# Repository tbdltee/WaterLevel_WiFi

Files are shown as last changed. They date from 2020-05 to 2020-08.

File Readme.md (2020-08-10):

# Wireless Water Level measurement
This project is using HC-SR04p ultrasonic to measure the water level and send to internet dashboard (using node-red).

## Current status: up
 * dashboard url: www.tbdltee.cloudns.cl:8890
 * Linenoify service was inactive. Plan to migrate to LINE-bot for notification. 
 
## Firmware Upload Status (Arduino/ESP8266)

* IOT001D0001 - 00410/00410/SDK2.2.1-Boot1.7/Core 2.6.3
* IOT001D0002 - 0040E/0040E/SDK2.2.1-Boot1.7/Core 2.4.2
* IOT001D0003 - 0040E/0040E/SDK2.2.1-Boot1.7/Core 2.6.3

## Release History
* 0040G
  * change server from tbdltee.thddns.net to myiot.tbdltee.cloudns.cl
  * dashboard url: www.tbdltee.cloudns.cl:8890
* 0040F
  * improve TCP response handling speed.
  * change iot server from tbdltee.duckddns.org:10722 to tbdltee.thddns.net:8895
  * change OTA server from tbdltee.duckddns.org:8890 to tbdltee.thddns.net:8890
  * BME280 auto reset if cannot read data for consecutive 5 times
  * Support Submersible 4-20mA Water Level Sensor
* 0040E
  * Support remote reboot device from Dashboard
* 0040D
  * fixed: WiFiConfig portal handling
	* WiFiConfig redirect page to root if page not found.
	* WiFiConfig portal show WiFi signal strength bar instead of text
	* ESP is now graceful shutdown. Make WiFi connection more stable.
	* Increase TCP timeout from 10s to 15s
	* Increase UDP timeout from 3s to 5s
	* restart node if cannot connect to internet for 1 day.
  * 3G TxiNET_LowBatt from 10 hrs to 6 hrs.
  * bugs fixed (Arduino) in RainCount debounce using millis(). millis() is not working while sleep. Change millis() to Debounce_counter
	* bugs fixed (Arduino) in %Batt calculation. limited min/max Volt to 3400/4100.
	* Arduino: Sent lastCM to internet instead of average value. Last 5 values use for STD DV calculation.
  * Rain_debounce_counter set to 150ms
  * Timer adjustment
  * Change method to get Batt level. Measure Vcc for stability and use Max A2-value as 100%. Decrease maxADC 50mV for every 7 days.
	* Increase Batt_0% from 3.4v to 3.6v to increase stability at low batt mode
* 0040C
  * Measure ADC of internal reference 1.1v and calc back to A2-ADC.
  * Support Battery auto-calibration.
  * Bug fixed when Tx come back from Power-Off state
* 0040B
  * Use hardware jumpper to select between 3G and WiFi profile
  * Change WiFi update interval from 5 to 10 min
  * Update with TCP, then use UDP if TCP failed.
  * Change device key to Sequence Number
  * device is sent with raw distance data. Water level is calculated on the server.
  * Support line notification
  * Support only BME280 to simplify the code. 
  * Support hPA measurement from BME280
  * Change tempC value from 0..100 to tempC+40 (0..125 -> -40..85) to support full range of BME280
* 00400
  * release based on Water_Level_v4

## About the code
The code consists of 4 sketches:
* Arduino_WiFi:       this is a code for Arduino Pro-Mini. Upload the code using USB-TTL adapter.
* ESP_NodeRed_WiFi:   this is a code for ESP8266-01. Upload the code using USB-TTL adapter or HTTP OTA.
* esp_fota.js:        NodeJS app for http OTA update.
* node-red_flow.json: Node-Red flow

Configure 3G-WiFi USB dongle for deivceID IOT-xxxxDyyy:
* ssid: IOT-xxxxDyyy-3G
* pass: IOT-xxxxDyyy-3G
* ssid broadcast: off
* Security Type: WPA2-Personal, WPA-algorithm: TKIP+AES
* DHCP: off
* 3G dongle IP/Subnet: 192.168.8.1/255.255.255.0

Configure Line Notification (de-preciated. Replaced by LINE-bot):
* Add 'Line Notify' as friend in LINE app.
* goto https://notify-bot.line.me/th/ and log-in with your LINE id
* Click menu on  the top-right of the page and select  'My Page'
* Click 'Generate Token'
* Enter 'Token name' and chat group to notify.
  * Token Name: My IOT
  * Chat Group: 1-on-1 chat with Line Notify
  * Click 'Generate Token'
* copy the token and update in the Deivce_list databased
* if no line token is define, LINE nitification will be disable for those devices.

## How to use:
* Each device has it own Device ID (IOT-xxxxDyyy)
  * Group ID: IOT-xxxx
  * ID: Dyyy
* Select internet access profile using Jumper:
  * open: 3G profile
  * short: WiFi profile
  * when WiFi profile is select, the previous WiFi configuration is used.
* 3G configutation: none
* WiFi configuration:
  * Power-off and then on the device
  * Wait until device enter config mode
  *	Connect to ssid: iotConfAP, pass:iot1234 (if ask)
  *	Open browser and goto http://192.168.4.1
  * Enter wifi info, SAVE and wait for device to reboot
* LED status:
  * Fast blink:   OTA
  * Flash:        modem power up
  * Double flash: Connecting to internet
  * Triple flash:	sending data
  
## Author

Teerapong S. –  [tbdltee@gmail.com]

Patent Pending (Reg.1701003801)

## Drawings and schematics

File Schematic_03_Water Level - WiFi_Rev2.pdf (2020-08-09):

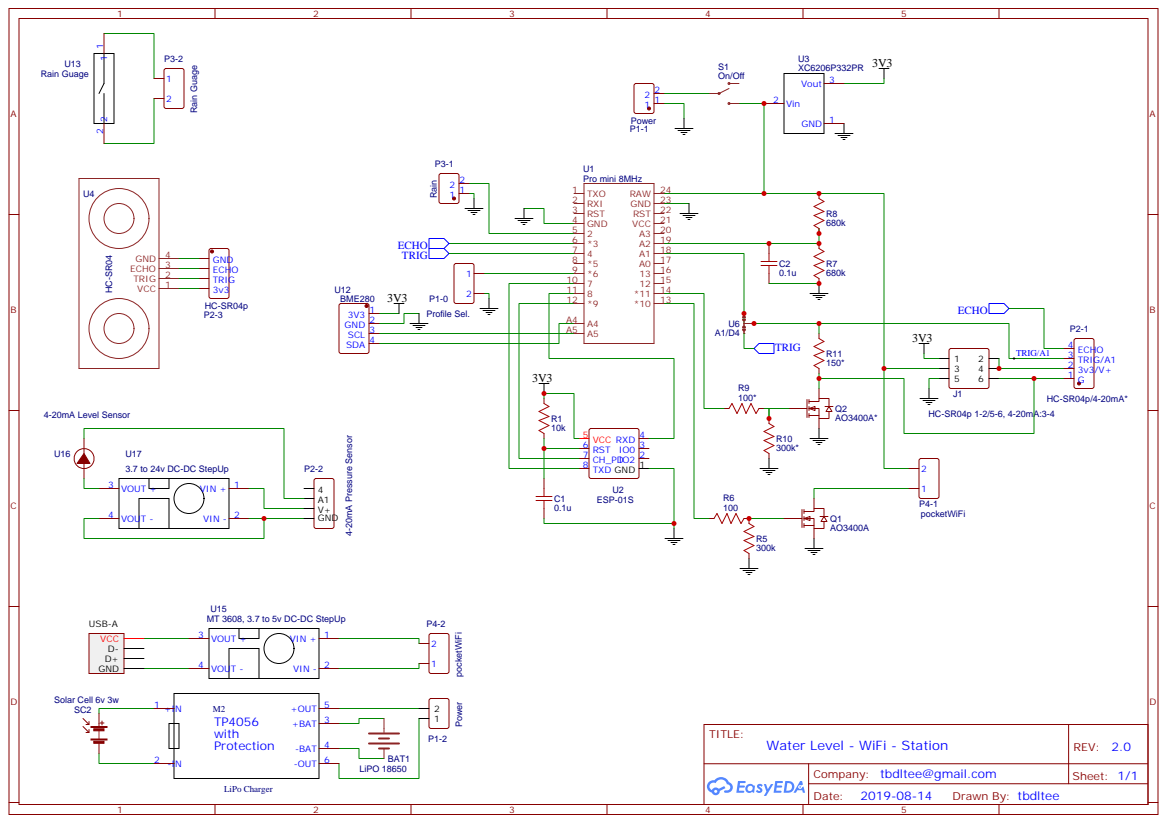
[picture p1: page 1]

Company: tbdltee@gmail.com

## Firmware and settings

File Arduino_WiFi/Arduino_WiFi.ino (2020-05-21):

#define stDEBUG             1               // Show Debug message. 0-no debug, 1-show debug, 2-debug using wifi profile
#define SENSOR_TYPE         0               // Distance Sensor:    0-Top-Down distanceCM (HC-R04), 1-Buttom-up 4-20mA, 2-reserved, 3-reserved
#define SENSOR_RAIN         1               // Rain Gauge Sensor:  0-not present, 1-present

// ================================= Node Info. ===========================================
// SW version 0040D 
const char* Device_GroupID  = "IOT-0001";   // Device_GroupID
const char* Device_ID       = "D001";       // Device ID

// =================================== Library Declaration ================================
#include "Node_Config.h"
#include <avr/wdt.h>          // library for default watchdog functions
#include <avr/interrupt.h>    // library for interrupts handling
#include <avr/sleep.h>        // library for sleep
#include <avr/power.h>        // library for power control
#include <NeoSWSerial.h>
#include <EEPROM.h>
#include <I2C.h>
#include <BME280_I2C.h>

#define inRange(x, a, b) (((a) <= (x)) && ((x) <= (b)))     // define macro if (x>=a) && (x<=b)
#define outRange(x, a, b) (((x) < (a)) || ((x) > (b)))      // define macro if (x<a) || (x>b)
#define BYTE2HEX(x) ((((x) > 0x0F)?"":"0") + String((x), HEX))
#define LEDon() digitalWrite(LED_BUILTIN, HIGH)
#define LEDoff() digitalWrite(LED_BUILTIN, LOW)
#define LEDflash() ({digitalWrite(LED_BUILTIN, HIGH); delay(10); digitalWrite(LED_BUILTIN, LOW);})
#define LEDtoggle() (digitalWrite(LED_BUILTIN, !digitalRead(LED_BUILTIN)))

// Timers & Counters
volatile uint8_t  cnt1secWDT  = 0;            // Counter for 1 sec
volatile uint8_t  INT0_btnCnt = 0;            // INT0 Debounce Counter 10x15 = 150ms, (millis() not working in sleep mode)
volatile uint16_t cntRemaining;               // how many times remain before wakeup and tx value, Volatile variable, to be able to modify in interrupt function
volatile uint16_t RainCount   = 0;            // rain sensor counter

uint8_t TxiNETcnt     = 0;                    // Counter to send data to internet. 0-Send data, 1..250-Normal/Low Batt, 251..254-Pwr-Off recovery, 255-never send, 
uint8_t Rapidcnt      = 128;                  // Counter of rapid update
uint32_t wakeup_time  = 0;
String iNETSerialmsg  = "";

NeoSWSerial iNETSerial(ESP_RxPin, ESP_TxPin); // RX, TX
BME280 myBME280;

void(* resetFunc) (void) = 0;                 //declare reset function @address 0

// ============================================================================================
void setup() {
  wdt_disable();
  delay (500);                                // startup delay to avoid power surge
# if (stDEBUG > 0)
  Serial.begin(57600);
#endif

  pinMode (Profile_SEL_Pin,  INPUT_PULLUP);
  pinMode (ESP_ENpin, OUTPUT);
  digitalWrite(ESP_ENpin, LOW);               // disable ESP8266
  pinMode (MODEM_ENpin, OUTPUT);
  digitalWrite(MODEM_ENpin, LOW);             // disable 3G/4G modem
  pinMode (LED_BUILTIN, OUTPUT);
  LEDoff();

  if ((digitalRead (Profile_SEL_Pin) == LOW) || (stDEBUG == 2)) {               // change from 3G to WiFi
    Device_Profile  = "WL";                   // use WiFi Profile
    ModemWaitTime   = 0;                      // wait for modem to power-up
    ModemPwrUpTime  = 50;                     // total modem power-up time 50s
    CMDdelayTime    = 0;                      // delay time after wifi connected
    WakeUpInterval  = 120;                    // device wake-up every 120s
    Batt_Interval   = 5040;                   // Batt re-calibration interval: 5 040 x 120 = 604 800 sec = 7 days
    iNET_ERR_RST    = 720;                    // Consecutive wifi error before node restart: 720 x 120 = 86 400 sec = 1 days
    TxiNET_LowBatt  = 60;                     // Send data to internet every 120min (WakeUpInterval x TxiNET_Normal)
    TxiNET_Normal   = 5;                      // Send data to internet every 10min (WakeUpInterval x TxiNET_Normal)
    printDEBUG (F("[S] == SYSTEM INIT (WiFi Profile) =="));
  } else {
    printDEBUG (F("[S] == SYSTEM INIT (3G Profile) =="));
  }
  printDEBUG ("[S] DeviceID: " + sysVar.DevID);
  pinMode (Profile_SEL_Pin,  INPUT);          // change pinMode to remove Internal R pullup
  
  randomSeed(get_rand_byte());
  iNetTx.seqNr = random(65536);
  iNETSerial.begin(19200);
  delay (200);
  Init_Peripheral();
  Initialize_wdt();                           // configure with reset interval 1 sec and start the watchdog.
  resetTxData ();
  sysVar.ssid = sysVar.DevID + "-" + String (Device_Profile);
  sysVar.pass = sysVar.ssid;
#if (SENSOR_TYPE == 1)
  EEPROM.get (0x00, ADC4mA);
#endif
}

void loop(void) {
  wakeup_time = millis();
  cntRemaining = WakeUpInterval * 1.2;
  updateBattState ();
  uint16_t PrevdistanceCM = TxData.lastCM;                            // save current distance value before new distance measurement
  measureDistanceCM ();                                               // single measure distance, every wake-up (3 min)
  checkLevelRapidChange (PrevdistanceCM);
  //printDEBUG ("[D] rangeCM-"+String(TxData.distanceIdx)+":"+String(TxData.lastCM) + ", Batt:"+String(iNetTx.BattLvl)+", RainCnt:"+String(RainCount)+", Rapidcnt:"+String(Rapidcnt));
  
  if (TxiNETcnt == 0) {                                 // Send data to internet
    updateData ();
    if (iNetTx.BattLvl <= BATTPowerSave) {
      TxiNETcnt = TxiNET_LowBatt;                       // if low batt, set TxInterval to TxiNET_LowBatt
    } else {
      TxiNETcnt = TxiNET_Normal;
    }
  }
  if (SYScnt.iNetRst > iNET_ERR_RST) {
    //printDEBUG ("[S] No iNET 24hr...Restart");
    delay (500);
    resetFunc();
  }
  sleep();
  TxiNETcnt--;
}

void checkLevelRapidChange (uint16_t PrevdistanceCM) {
  uint16_t LvlRapidCM = LvlCMChange * WakeUpInterval / 60;            // calc cm/min to cm threshold per measurement
  uint16_t lowerRapid =  (PrevdistanceCM > LvlRapidCM) ? PrevdistanceCM - LvlRapidCM: 0;
  if (TxData.lastCM  > 0) {
    if (TxData.lastCM > (PrevdistanceCM + LvlRapidCM)) {              // distance above threshold -> Rapid change increase counter
      Rapidcnt++; SYScnt.nonRapid = 0;
    } else if (TxData.lastCM < lowerRapid) {                          // distance below threshold -> Rapid change decrease counter
      Rapidcnt--; SYScnt.nonRapid = 0;
    } else {                                                          // distance within threshold range -> increase non-rapid counter
      SYScnt.nonRapid++;
      if (SYScnt.nonRapid > 10) {                                     // if non-rapid counter > 10, reset rapid change counter
        Rapidcnt = 128; SYScnt.nonRapid = 0;
      }
    }
    if (outRange (Rapidcnt, 125, 131)) {                              // if 3 consecutive rapid change, update inet/override BATTPowerOff
      TxiNETcnt = 0; Rapidcnt = 128;
      sysVar.NodeStatus |= 0x08;                                      // Set Rapid Update flag
    }
  }
}

void updateBattState (void) {
  SYScnt.BattreCal++;
  iNetTx.BattLvl = getBatt();                                       // get %battery
  //printDEBUG ("[Batt] max-mV:" + String(sysVar.maxAmVolt) + ", BattCnt:"+ String(SYScnt.BattreCal) + " ,TxiNETcnt:"+ String(TxiNETcnt));
  LEDflash ();
  if (iNetTx.BattLvl <= BATTPowerOff) {                             // if Batt_PowerOff, set TxiNETcnt = 254 (never update iNET)
    TxiNETcnt = 255;
    //printDEBUG ("[D] Batt Power-Off..");
   return;
  }
  if (TxiNETcnt > 250) {                                            // if Batt in Power_off state, check wakeup condition?
    if (iNetTx.BattLvl > BATTPowerSave) {                           // if Batt Level above Power_Save, decrease counter
      //printDEBUG ("[D] Batt Recovery.." + String (TxiNETcnt - 251));
    } else {                                                        // Tx in Power-Save with below Power_Save threshold -> hold in receovery state
      TxiNETcnt = 254;
      //printDEBUG ("[D] Batt Reovery-hold..");
    }
    if (TxiNETcnt == 251) {                                         // Batt above Power_Save for 4 consecutive WakeupInterval, send data to iNET
      if (iNetTx.BattLvl <= BATTPowerSave) sysVar.NodeStatus |= 0x10;
      else sysVar.NodeStatus &= 0xEF;
      TxiNETcnt = 0;
    }
    return;
  }
  // not in recovery state
  if (iNetTx.BattLvl <= BATTPowerSave) {                            // if Batt Level above Power_Save, decrease counter
    if ((sysVar.NodeStatus & 0x10) == 0) {                          // Normal ==> Power Save
      sysVar.NodeStatus |= 0x10;                                    // Low Batt
      if (TxiNETcnt > 0) TxiNETcnt += (TxiNET_LowBatt - TxiNET_Normal);
      //printDEBUG ("[D] Batt Norm -> PwrSave...new TxiNETcnt:" + String (TxiNETcnt));
    }
  } else {                                                          // Normal state
    if (sysVar.NodeStatus & 0x10) {                                 // Power Save ==> Normal
      sysVar.NodeStatus &= 0xEF;                                    // Normal Batt
      TxiNETcnt = TxiNET_LowBatt - TxiNETcnt;
      if (TxiNETcnt >= TxiNET_Normal) TxiNETcnt = 0;
      else TxiNETcnt = TxiNET_Normal - TxiNETcnt;
      //printDEBUG ("[D] Batt PwrSave -> Norm...new TxiNETcnt:" + String (TxiNETcnt));
    }
  }
}

void resetTxData (void) {
  iNetTx.LvErrType      = 1;
  iNetTx.distanceCM     = 0;
  iNetTx.TempC          = 127;
  iNetTx.RH             = 127;
  iNetTx.hPAx100        = 0xFFFF;
  iNetTx.LvSampleRead   = 0;
  iNetTx.iNETattempt    = 0;
  iNetTx.iNETDNSfail    = 0;
  iNetTx.iNETSentfail   = 0;
  iNetTx.iNETWififail   = 0;
  iNetTx.iNETHostfail   = 0;
  if ((sysVar.NodeStatus & 0x04) == 0) iNetTx.iNETNoResp = 0;
}

void getSensorData (void) {       // calculate average distance and get weather data
  
  return;
  
  getAvgDistance ();              // iNetTx.distanceCM and iNetTx.errType were updated
  float TempC = 127, RH = 127, Pa = 0;
  readBME280 (myBME280, TempC, Pa, RH);
  if (myBME280.ready < 1) {
    TempC = 127; RH = 127; Pa = 0;
  }
  if (isnan(TempC)) TempC = 127;
  if (isnan(RH)) RH = 127;
  if (isnan(Pa)) Pa = 0;
  iNetTx.TempC    = (uint8_t)((TempC == 127)?127:(TempC+40));
  iNetTx.RH       = (uint8_t)RH;
  iNetTx.hPAx100  = (uint16_t)(outRange(Pa, 50000, 115500)?0xFFFF:(Pa-50000.0));
  if ((TempC == 127)||(RH == 127)||(Pa == 0)) SYScnt.BME280err++;
  else SYScnt.BME280err = 0;
  if (SYScnt.BME280err > BME280err_ALLOW) {
    myBME280.reset();
    BME280_Init (myBME280);
    SYScnt.BME280err = BME280err_ALLOW - 1;
  }
}

String getValue(String data, char separator, int index) {
  int found = 0;
  int strIndex[] = {0, -1};
  int maxIndex = data.length()-1;
  for (int i = 0; i <= maxIndex && found <= index; i++) {
    if (data.charAt(i) == separator || i == maxIndex) {
      found++;
      strIndex[0] = strIndex[1]+1;
      strIndex[1] = (i == maxIndex) ? i+1 : i;
    }
  }
  return found>index ? data.substring(strIndex[0], strIndex[1]) : "";
}

uint16_t calcSleepTime (void) {                   // calculate sleep time (sec) to prevent wake-up time > WakeUpInterval, e.g OTA
  uint16_t runningTime = (uint16_t)((millis() - wakeup_time)/1000L);
  runningTime = runningTime % WakeUpInterval;     // calc running time of the last cycle to ensure that runningtime < WakeUpInterval
  return (WakeUpInterval - runningTime);
}

String uint16_t2HEX (uint16_t value) {
  String result = BYTE2HEX((uint8_t)((value & 0xFF00) >> 8));
  result += BYTE2HEX((uint8_t)(value & 0x00FF));
  return result;
}

// ========================= Generate true random number, use for RandomSeed() ============================
int GetTemp (void) {
  unsigned int wADC;
  ADMUX = (_BV(REFS1) | _BV(REFS0) | _BV(MUX3));
  ADCSRA |= _BV(ADEN);  // enable the ADC
  delay(20);            // wait for voltages to become stable.
  ADCSRA |= _BV(ADSC);  // Start the ADC
  while (bit_is_set(ADCSRA,ADSC));
  wADC = ADCW;
  return (wADC);
}

int coin_flip(void) {
  int little_bit;
  return little_bit = (GetTemp() & 1);
}

int getFairBit(void) {
  while(1) {
    int a = coin_flip();
    if (a != coin_flip()) return a;
  }
}

int get_rand_byte(void){
  int n=0;
  int bits = 7;
  while (bits--) {
    n<<=1; 
    n |= getFairBit();
  }
  return n;
}

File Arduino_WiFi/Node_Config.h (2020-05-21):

// =================================== Paramteres ================================
String Device_Profile   = "3G";         // 3G profile parameter
uint8_t ModemWaitTime   = 10;           // wait for modem to power-up
uint8_t ModemPwrUpTime  = 75;           // total modem power-up time 75s
uint8_t CMDdelayTime    = 5;            // delay time after wifi connected
uint16_t WakeUpInterval = 300;          // device wake-up every 5min
uint16_t Batt_Interval  = 2016;         // Batt re-calibration interval: 2016 x 300 = 604 800 sec = 7 days
uint16_t iNET_ERR_RST   = 288;          // Consecutive wifi error before node restart: 288 x 300 = 86 400 sec = 1 days
uint8_t TxiNET_LowBatt  = 72;           // Max:250, Send data to internet every 6hr (WakeUpInterval x TxiNET_Normal)
uint8_t TxiNET_Normal   = 6;            // Max:250, Send data to internet every 30min (WakeUpInterval x TxiNET_Normal

// Sensor pin: |GND|Rain| |SR04_TRIG|SR04_ECHO|GND|A1|5V|3V3|
// pin assignment
const uint8_t RainGauge_pin   = 2;
const uint8_t BattMeasurepin  = A2;
const uint8_t Profile_SEL_Pin = 6;            // Profile Select: 0-WiFi, 1-3G

#if (SENSOR_TYPE == 0)                        // HC-SR04
  const uint8_t SR04_TRIGpin  = 3;
  const uint8_t SR04_ECHOpin  = 4;
  const uint16_t LvlCMChange  = 10;           // Update data asap if levelCM change > 10 cm/min
#elif (SENSOR_TYPE == 1)                      // 4-20mA Buttom-up Sensor ,e.g Sumersible water level sensor
  #define ADC4mAINIT            192
  const uint8_t  Level_pin    = A1;
  const uint8_t  Level_EN_pin = 11;
  const uint16_t LvlCMChange  = 20;           // Update data asap if levelCM change > 10 cm/min --> ADC=20
  uint16_t       ADC4mA       = ADC4mAINIT;   // Normalize ADC value 4mA @3.3v. Run ADC_Cal.ino sketch to get value
  uint8_t        minADC4mAcnt = 0;            // consecutive counter of ADC below ADC4mA
#endif

const uint8_t ESP_RxPin       = 7;            // to ESP Tx
const uint8_t ESP_TxPin       = 8;            // to ESP Rx
const uint8_t ESP_ENpin       = 9;            // ESP enabled (CHPD pin)
const uint8_t MODEM_ENpin     = 10;           // Pocket WiFi enable pin

// ============================= Threshold =============================
const uint8_t  OTA_ATTEMPT_ALLOW  = 5;        // ESP8266 http OTA: 0-OTA not allow, 1..7-#of OTA failure allow
const uint8_t  BATTPowerSave      = 30;       // %Batt to operate in power save mode
const uint8_t  BATTPowerOff       = 10;       // %Batt to operate in power off
const uint16_t BATT_V000          = 3600;     // Batt mVolt as 0%Batt, 3.40v = Vcc 3.15v + 0.25v drop voltage
const uint8_t  BME280err_ALLOW    = 5;        // Consectutive BME280 read error before BME280 reset

// ============================= Variable =============================
struct counter {
  uint8_t  OTAallow     = OTA_ATTEMPT_ALLOW;  // #OTA update failure before stop OTA. reset when data sent with no OTA req.
  uint8_t  nonRapid     = 0;                  // Counter of consecutive non-rapid count to reset Rapidcnt counter
  uint8_t  BME280err    = 0;                  // consecutive error reading BME280
  uint16_t BattreCal    = 0;                  // batt re-calibrate counter
  uint16_t iNetRst      = 0;                  // Consecutive wifi error counter before node restart
} SYScnt;

struct sysParaType {                          // system parameters
  String   DevID          = String(Device_GroupID) + String(Device_ID);
  String   ssid           = "";
  String   pass           = "";
  uint8_t  NodeStatus     = 0x80;             // Node Status: 7654 3210, 7:node reboot, 6:Rain Sensor-ready, 5:Weather sensor, 4:Low Batt, 3:Rapid Update, 2:Server-No response, 1/0: Send retry
  uint16_t WiFiConfTime   = 600;              // Wifi Config mode time-out, 5 min. Allow only after Arduino reset
  uint16_t maxAmVolt      = 4100;             // max mV of ADC value
} sysVar;

struct NodeDataType {
  uint16_t lastCM         = 0;                // lastast distanceCM
  uint8_t  distanceIdx    = 0;                // index of distanceMM[]
  uint16_t accRainCount   = 0;                // accumulated rain counter
  uint16_t distanceCM[5]  = { 0,0,0,0,0 };
} TxData;
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

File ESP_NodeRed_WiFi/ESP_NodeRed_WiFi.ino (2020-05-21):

#include <Arduino.h>
#include "Node_Config.h"
#include <EEPROM.h>
#include <ESP8266httpUpdate.h>
#include <ESP8266WiFi.h>
#include <WiFiUdp.h>
#include <ESP8266WebServer.h>

uint8_t ESPstatus = 0;
uint8_t strCMDidx = 0;
uint8_t OTAallowCnt = 0;
String CMDSerial = "", strCMD = "", devID = "", sendTxt = "", SEQNr = "";
uint32_t prevtime = 0;

char ssid[32] = "test";
char pass[32] = "test";

ESP8266WebServer server(80);              // local web server for configuration portal
IPAddress Host_addr(255,255,255,255);
WiFiUDP udpClient;

// ======================== Program Setup Part ===========================
void setup() {
  WiFi.mode (WIFI_OFF);
  WiFi.forceSleepBegin();
  delay (1);                                              // turn-off RF at Power-up
  
  pinMode(LED_BUILTIN, OUTPUT);
  digitalWrite(LED_BUILTIN, HIGH);                        // turn-off LED
  
  Serial.begin (19200);                                   // Init COMM to communicate with Arduino
  delay (100);
  Serial.println ("\r\n\r\nC,ESP init");
  prevtime = millis();
  while (((millis() - prevtime) < 10000L) && (ESPstatus == 0)) {
    monitorSerial();                                        // wait for command from Arduino
  }
  if (ESPstatus == 0) {                                     // time-out
    ESP.restart();
  } else if (ESPstatus == 1) {                              // coonect with 3G profile
    Serial.println ("C,connecting 3G with " + String(ssid));
    Connect2WiFi (0);
  } else if (ESPstatus == 6) {                              // connect using WiFi profile
    Serial.println ("C,connecting wifi.." + String(ssid));
    Connect2WiFi (1);
  } else if (ESPstatus == 7) {                              // connect using WiFi Manager
    ReadWiFiConfig ();                                      // use local ssid/pass
    Serial.println ("C,connecting wifi with wifiConfig.." + String(ssid));
    Connect2WiFi (2);
    if (ESPstatus == 2) Serial.println ("C,Config ok," + String (ssid) + ","+String(pass));
  }
  
  if (ESPstatus == 2) {                                     // wifi connected
    Serial.println ("C,wifi ready,IP:" + WiFi.localIP().toString());
    udpClient.begin(dataPort);
  } else if (ESPstatus == 7) {                              // wifi.begin failed and in wifi config mode
    Serial.println ("C,Enter wifi config mode");
    ESPstatus = 5;
    startConfigPortal (600);                                // startConfigPortal result in ESP rertart.
  } else {
    Serial.println ("C,Wifi connect error..TIME-OUT");
    Serial.println ("C,ESP ready to shut-down");
    WiFi.disconnect ();
    delay (80);
    ESP.deepSleep (10000000L, WAKE_RF_DISABLED);
    WiFi.forceSleepBegin();
    delay (30000);
    ESP.restart();
  }
  ReadHostAddr ();                                          // read Host address from EEPROM
}
//================= end of setup, ESPstate-2 ==============================

void loop() {
  uint8_t HostlookupFail = 0;
  if (ESPstatus == 2) {                               // wifi connected
    while (ESPstatus != 4) monitorSerial();           // wait for completed RCV Data
    ESPstatus = 10;                                   // Move Connecting to Hostname resolving State
    prevtime = millis() - 12000;
  } else if (ESPstatus == 10) {
    ResolveHostName ();
  } else if (ESPstatus == 11) {                       // Host Address presented
    sendData2iNet ();
    ESPstatus = 2;                                    // move to Wait for CMD
  }
  monitorSerial();
}

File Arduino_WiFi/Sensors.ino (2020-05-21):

void Init_Peripheral() {
#if (SENSOR_TYPE == 0)            // HC-SR04
  pinMode(SR04_TRIGpin, OUTPUT);
  digitalWrite(SR04_TRIGpin, LOW);
  pinMode(SR04_ECHOpin, INPUT);
#elif (SENSOR_TYPE == 1)          // 4-20mA Buttom-up Sensor ,e.g Sumersible water level sensor
  pinMode (Level_EN_pin, OUTPUT);
  digitalWrite(Level_EN_pin, LOW);
#endif

  pinMode(BattMeasurepin, INPUT);
  BME280_Init(myBME280);
  if (myBME280.ready > 0) {
    sysVar.NodeStatus |= 0x20;
    printDEBUG ("[S] Temp/RH: BME280..OK");
  } else {
    printDEBUG ("[S] Temp/RH: no BME280");
  }

  RainCount = 0;
#if (SENSOR_RAIN == 1)
  printDEBUG ("[S] Rain Gauge..OK");
  sysVar.NodeStatus |= 0x40;
  pinMode(RainGauge_pin, INPUT_PULLUP);                 // Set INT0 back to input-pullup
  attachInterrupt(digitalPinToInterrupt(RainGauge_pin), RainGaugeCount, FALLING);
#else
  printDEBUG ("[S] no Rain Gauge.");
#endif
  printDEBUG ("[S] WakeUpInterval: " + String(WakeUpInterval) + "\r\n");
}

uint8_t getBatt(void) {
  uint16_t Avalue   = 0;                                                  // ADC 0..1023, read 64 loop => ADC value = 0..65472
  uint16_t AmVolt   = 0;
  uint16_t A11Value = readADC11();                                        // read ADC @1.1v reference  
  uint16_t mVcc = map(1023, 0, A11Value, 0, 1100);                        // calculate Vcc

  if (sysVar.maxAmVolt < 4100) sysVar.maxAmVolt = 4100;                   // init maxAmVolt to 4.10v as 100%
  for (uint8_t i = 0; i < 64; i++) Avalue += analogRead(BattMeasurepin);
  AmVolt = map (Avalue, 0, 65472, 0, mVcc) * 2;                           // Calculate A2 volt. x2 due to R-divider
  if (SYScnt.BattreCal >= Batt_Interval) {                                // re-calibration counter expire,
    SYScnt.BattreCal = 0;
    sysVar.maxAmVolt -= 50;                                               // reduce maxAmVolt 50mV
  }
  
  if (AmVolt > sysVar.maxAmVolt) sysVar.maxAmVolt = AmVolt;
  // printDEBUG ("[B] Batt_cnt: "+ String(SYScnt.BattreCal)+" ("+ String(Batt_Interval)+"), Vcc: "+ String(mVcc)+", A-mV: "+ String(AmVolt)+", Amax-mV: "+ String(sysVar.maxAmVolt));
  if (AmVolt <= BATT_V000) {
    return 0;  
  } else {
    return (uint8_t)map(AmVolt, BATT_V000, sysVar.maxAmVolt, 0, 100);
  }
}

uint16_t readADC11() {          // set ADC reference to Vcc and read ADC of internal 1.1V reference
  #if defined(__AVR_ATmega32U4__) || defined(__AVR_ATmega1280__) || defined(__AVR_ATmega2560__)
    ADMUX = _BV(REFS0) | _BV(MUX4) | _BV(MUX3) | _BV(MUX2) | _BV(MUX1);
  #elif defined (__AVR_ATtiny24__) || defined(__AVR_ATtiny44__) || defined(__AVR_ATtiny84__)
    ADMUX = _BV(MUX5) | _BV(MUX0);
  #elif defined (__AVR_ATtiny25__) || defined(__AVR_ATtiny45__) || defined(__AVR_ATtiny85__)
    ADMUX = _BV(MUX3) | _BV(MUX2);
  #else
    ADMUX = _BV(REFS0) | _BV(MUX3) | _BV(MUX2) | _BV(MUX1);
  #endif  

  delay(2);                         // Wait for Vref to settle
  ADCSRA |= _BV(ADSC);              // Start conversion
  while (bit_is_set(ADCSRA,ADSC));  // measuring

  uint8_t low  = ADCL;              // must read ADCL first - it then locks ADCH  
  uint8_t high = ADCH;              // unlocks both
  uint16_t result = (high<<8) | low;
  return result;
}

void getAvgDistance (void) {        // average distace value in buffer to send to internet
  uint8_t i, countDistance1 = 0;
  uint16_t sumDistance = 0, sumErr = 0;
  
  iNetTx.LvSampleRead = TxData.distanceIdx;
  if (TxData.distanceIdx > 5) TxData.distanceIdx = 5;
  for (i = 0; i < TxData.distanceIdx; i++) {
    if (TxData.distanceCM[i] > 0) {
      sumDistance += TxData.distanceCM[i];
      countDistance1++;
      if (TxData.lastCM > TxData.distanceCM[i]) sumErr += (TxData.lastCM - TxData.distanceCM[i]);
      else sumErr += (TxData.distanceCM[i] - TxData.lastCM);
    }
  }
  if (countDistance1 == 0) {
    iNetTx.distanceCM = 0;
    iNetTx.LvErrType = 1;                         // cannot read distance
  } else {
    iNetTx.distanceCM = TxData.lastCM;            // send lastCM
    if (countDistance1 <= 3) {
      iNetTx.LvErrType = 2;                       // too low #sample
    } else {
      if ((sumErr * 2) > sumDistance) {           // Err > 50% - too high standard deviation
        iNetTx.LvErrType = 3;
      } else {
        iNetTx.LvErrType = 0;
      }
    }
  }
}

void measureDistanceCM(void) {                                // main function to get distance from short range and long range sensor
  TxData.lastCM = getDistanceSesnor();                        // get distance from Sensor
  TxData.distanceCM[TxData.distanceIdx % 5] = TxData.lastCM;  // keep only last 5 samples
  TxData.distanceIdx++;
}

#if (SENSOR_TYPE == 0)                                // HC-SR04
uint16_t getDistanceSesnor() {                       // Get distance (mm), single ping from HC-SR04+
  uint16_t result = 0;
  uint32_t pulse_width;
  digitalWrite(SR04_TRIGpin, LOW);
  delayMicroseconds(2);
  digitalWrite(SR04_TRIGpin, HIGH);                   // Hold the trigger pin high for at least 10 us
  delayMicroseconds(10);
  digitalWrite(SR04_TRIGpin, LOW);
  delayMicroseconds(120);                             // delay at least 2cm (120 us pulse)
  pulse_width = pulseIn(SR04_ECHOpin, HIGH, 23280);   // Returns the pulse width in uS or 0 if over 400 cm (23200 us pulse)
  result = (uint16_t)(((float)pulse_width)/58.2);     // return distance, cm
  if (inRange(result, 2, 400)) return result;         // valid distance is 3-400cm 
  return 0;
}
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

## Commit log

2018-08-09 Base on Water_Level_DirectWiFi_v4.1
    [Water_DirectWiFi.fzz]
2018-08-12 Update Fritzing Schematic Select device_profile using jumper (3G-float/WiFi-connected)
    [Water_DirectWiFi.fzz]
2018-08-13 - Send rain accumulated Counter to node-red (no counter reset) - Support accumulated rain volume withn 60min, 24hr - rain in MM calculated at node-red instead of Arduino
    [Arduino_WiFi.ino, Node_Config.h, Sensors.ino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]
2018-08-31 See readme.md for update
    [Water_DirectWiFi.fzz]
2018-10-17 Support battery auto-calibration. Fix error when device go back from Power-Off-state
    [Arduino_WiFi.ino, ESP_NodeRed_WiFi.ino, Node_Config.h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]
2019-09-16 update to 0040F
    [Water_DirectWiFi.fzz]
2020-08-09 Update Readme.md
    Update on current project status
2020-08-09 add schematic file
